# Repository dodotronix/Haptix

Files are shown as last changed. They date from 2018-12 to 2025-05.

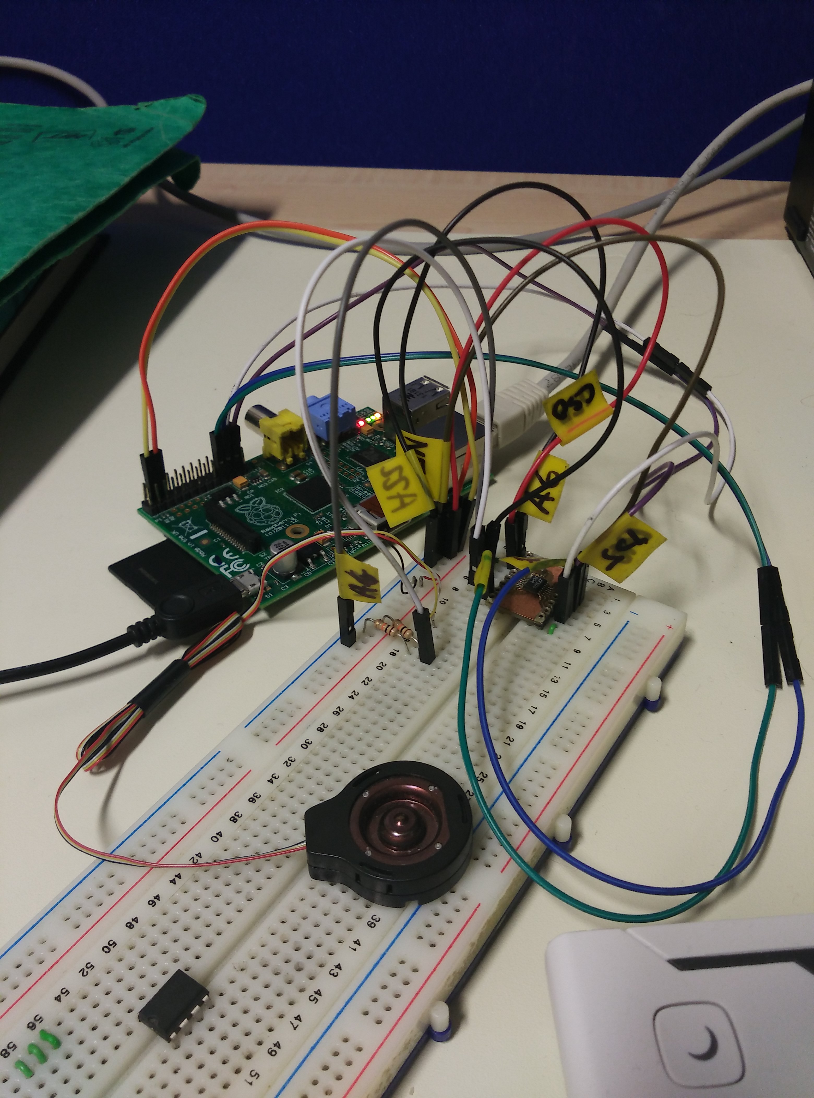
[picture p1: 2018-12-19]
analysis/hw/IMG_20181219_160500.jpg

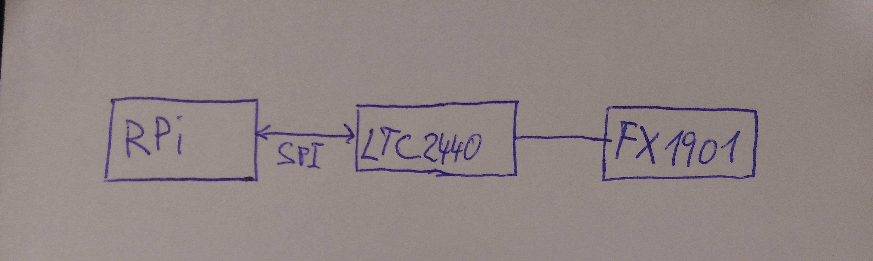
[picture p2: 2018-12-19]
analysis/hw/IMG_20181219_160821.jpg

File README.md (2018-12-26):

## HAPTIX

### INSTALL
* install Archlinux on SD card (https://archlinuxarm.org/platforms/armv6/raspberry-pi)
* turn on RPi
* use ssh or keyboard and display to continue in installation

* update system with
> pacman -Syu
* download 
> pacman -S python 
* download snap shot from link: https://aur.archlinux.org/packages/python-spidev/
* open terminal -> cd /path/to/file -> tar xzf file-name -> cd file-name ->
makepkg -s -> sudo pacman -U name-of-file.pkg.tar.xz
* copy test.py to raspberry
* cd /path/to/test.py
* chmod +x test.py
* ./test.py
* you select functions in script, which you want to run

### NOTES
* spidev doc (https://github.com/doceme/py-spidev)
* raspberry ssh command: ssh alarm@10.0.4.x, password: "alarm" (custom settings)
* sudo iptables -t nat -vnL
* setup.sh creates nat, starts dhcpcd, launchs ssh (parameters: on/off)

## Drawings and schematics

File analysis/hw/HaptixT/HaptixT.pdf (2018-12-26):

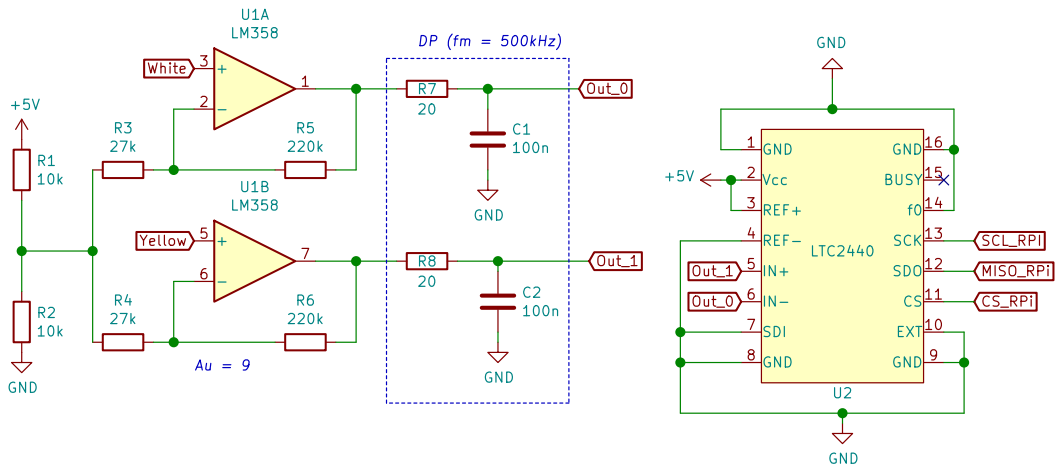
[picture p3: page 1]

File: HaptixT.sch Sheet: /
Id: 1/1 Title:

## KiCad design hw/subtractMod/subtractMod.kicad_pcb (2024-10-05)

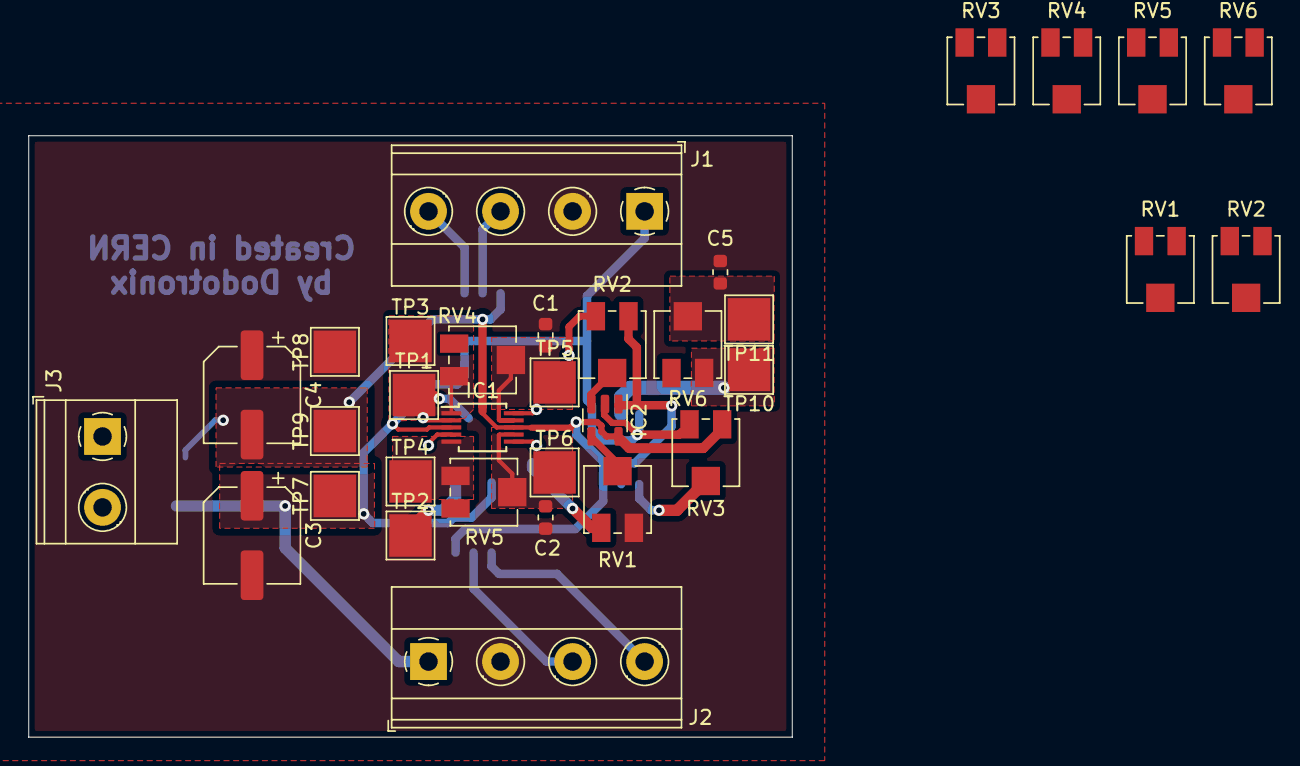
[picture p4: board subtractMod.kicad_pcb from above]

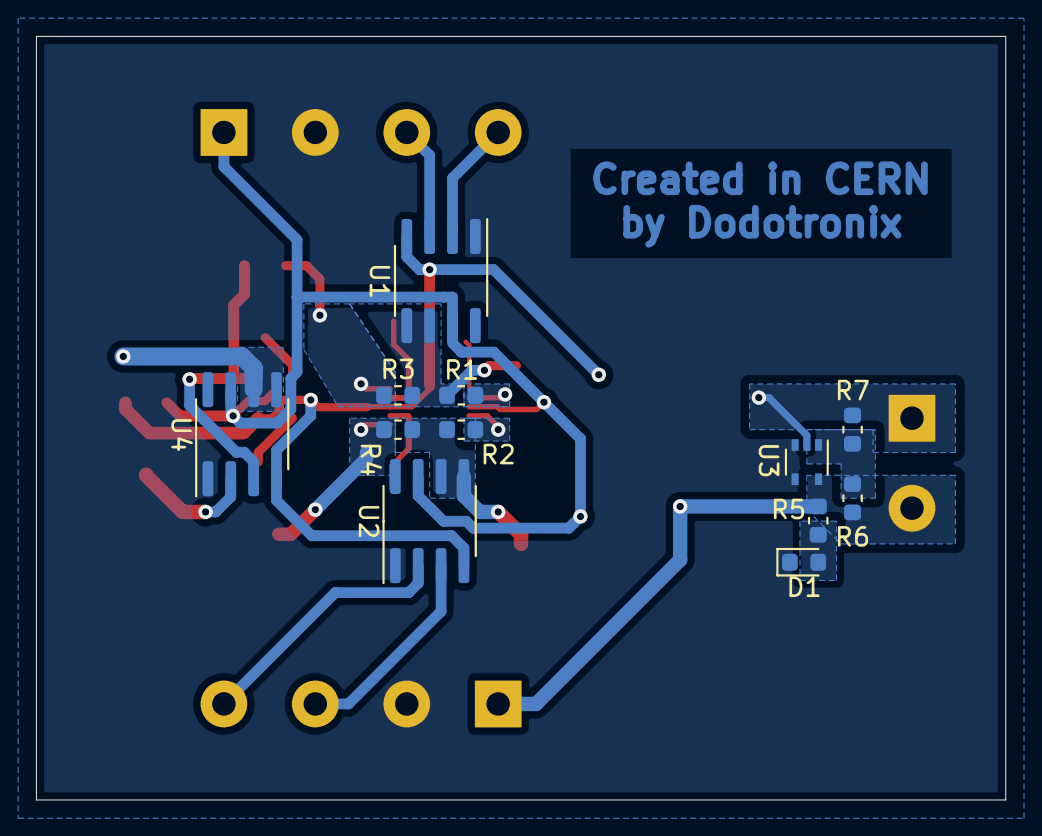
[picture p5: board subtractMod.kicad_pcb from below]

Board: 2 copper layers, 53.8 x 42.4 mm, 45 parts (12 on the bottom side), 25 nets.

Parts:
C1, C2, C5: C; C_0603_1608Metric
C3, C4: 47u; CP_Elec_6.3x5.9
D1: LED; LED_0603_1608Metric
IC1: AD8244; MSOP-10_3x3mm_P0.5mm
IC2: LMP2011; SOT-23-5
J1, J2: Screw_Terminal_01x04; TerminalBlock_Phoenix_MKDS-1,5-4-5.08_1x04_P5.08mm_Horizont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
J3: Screw_Terminal_01x02; TerminalBlock_Phoenix_MKDS-1,5-2_1x02_P5.00mm_Horizontal
R1, R2, R3, R4: 0R; R_0603_1608Metric
R5: R; R_0603_1608Metric
R6, R7: 10k; R_0603_1608Metric
RV1, RV2, RV3, RV4, RV5, RV6: R_POT_TRIM; Potentiometer_Bourns_3314J_Vertical
RV1#2, RV2#2, RV3#2, RV4#2, RV5#2, RV6#2: R_Potentiometer_Trim; Potentiometer_Bourns_3314J_Vertical
TP1, TP2, TP3, TP4, TP5, TP6, TP7, TP8, TP9, TP10, TP11: TestPoint; TestPoint_Pad_3.0x3.0mm
U1, U2, U4: AD8276; SOIC-8_3.9x4.9mm_P1.27mm
U3: TLV6001DCK; SOT-353_SC-70-5

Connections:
+5V: C3.1, IC1.3 (+V), IC2.5 (+V), J1.1, J2.1, J3.2, R5.1, R6.1, RV3.3, RV5#2.1, TP7.1, U1.7 (V+), U2.7 (V+), U3.5 (V+), U4.7 (V+)
-5V: C4.2, IC1.8 (-V), IC2.2 (-V), J3.1, R7.2, RV3.1, RV5#2.3, TP9.1, U1.4 (V-), U2.4 (V-), U3.2 (V-), U4.4 (V-)
/Input_channel/chan1_out: IC1.4 (OutB), R3.1, RV3#2.3
/Input_channel/chan2_out: IC1.9 (OutD), R4.1, RV4#2.1
/Input_channel/sensA_out: R1.2, R3.2, TP1.1, U1.5 (SENSE), U1.6
/Input_channel/sensB_out: R2.2, R4.2, TP2.1, U2.5 (SENSE), U2.6
GND: C1.2, C2.2, C3.2, C4.1, C5.2, D1.1 (K), J1.2, J2.2, RV1.3, RV4#2.3, TP8.1, U1.1 (REF), U2.1 (REF), U3.3 (-), U3.4, U4.1 (REF)
unnamed: C5.1, RV6.2, RV6#2.2, TP11.1
unnamed: D1.2 (A), R5.2
unnamed: IC1.1 (InA), R1.1
unnamed: IC1.2 (OutA), RV1#2.1, TP3.1
unnamed: C1.1, IC1.5 (InB), RV1#2.2, TP5.1
unnamed: IC1.6 (InC), R2.1
unnamed: IC1.7 (OutC), RV2#2.1, TP4.1
unnamed: C2.1, IC1.10 (InD), RV2#2.2, TP6.1
unnamed: IC2.3 (V+), RV3#2.2
unnamed: IC2.4 (V-), RV4#2.2
unnamed: IC2.1 (Vout), RV3#2.1, U4.3 (+)
unnamed: J1.3, U1.3 (+)
unnamed: J1.4, U1.2 (-)
unnamed: J2.3, U2.3 (+)
unnamed: J2.4, U2.2 (-)
unnamed: R6.2, R7.1, U3.1 (+)
unnamed: RV5#2.2, U4.2 (-)
unnamed: RV6#2.1, TP10.1, U4.5 (SENSE), U4.6

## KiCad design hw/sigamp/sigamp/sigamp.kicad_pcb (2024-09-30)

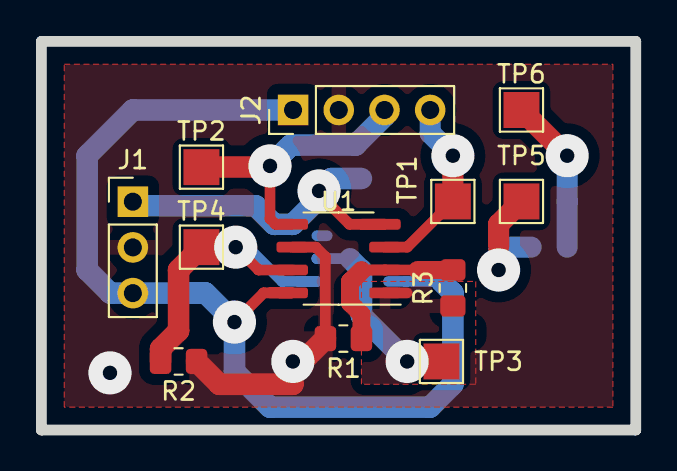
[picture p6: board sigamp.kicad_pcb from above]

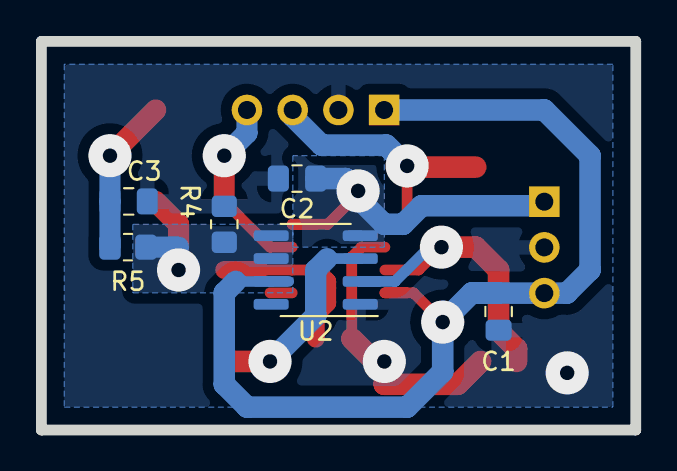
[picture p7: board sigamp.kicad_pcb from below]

Board: 2 copper layers, 33.0 x 21.6 mm, 18 parts (6 on the bottom side), 10 nets.

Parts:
C1, C2: 100n; C_0805_2012Metric_Pad1.18x1.45mm_HandSolder
C3: C; C_0805_2012Metric_Pad1.18x1.45mm_HandSolder
J1: Conn_01x03; PinHeader_1x03_P2.54mm_Vertical
J2: Conn_01x04; PinHeader_1x04_P2.54mm_Vertical
R1, R2, R3, R4, R5: R; R_0805_2012Metric_Pad1.20x1.40mm_HandSolder
TP1, TP2, TP3, TP4, TP5, TP6: TestPoint; TestPoint_Pad_2.0x2.0mm
U1: LM358; SO-8_3.9x4.9mm_P1.27mm
U2: AD8276; SOIC-8_3.9x4.9mm_P1.27mm

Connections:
+5V: C1.1, J1.3, J2.1, U1.8 (V+), U2.7 (V+)
-5V: C2.1, J1.1, U1.4 (V-), U2.4 (V-)
/s+: J2.4, TP1.1, U1.3 (+)
/s-: J2.3, TP2.1, U1.5 (+)
GND: C1.2, C2.2, C3.2, J1.2, J2.2, R1.2, R2.1, R4.1, U1.6 (-), U2.1 (REF)
unnamed: C3.1, R5.1, TP6.1
unnamed: R1.1, R3.2, U1.2 (-)
unnamed: R2.2, TP4.1, U1.7, U2.2 (-)
unnamed: R3.1, TP3.1, U1.1, U2.3 (+)
unnamed: R4.2, R5.2, TP5.1, U2.5 (SENSE), U2.6

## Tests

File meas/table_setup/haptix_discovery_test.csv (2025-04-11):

#Digilent WaveForms Oscilloscope Acquisition
#Device Name: Discovery3
#Serial Number: SN:210415BCB78D
#Date Time: 2025-03-28 16:28:17.887.605.610
#Sample rate: 10000Hz
#Samples: 16384
#Trigger: Source: Channel 1 Type: Edge Condition: Rising Level: 50 mV Hyst.: Auto HoldOff: 0 s
#Channel 1: Range: 1 V/div Offset: 0 V Probe: 10 X Sample Mode: Average
#Channel 2: Range: 200 mV/div Offset: 0 V Probe: 10 X Sample Mode: Average
Time (s) | Channel 1 (V) | Channel 2 (V)
-0.8191273972602741 | 0.03404938981463987 | 0.01975503185556442
-0.8190273972602741 | 0.03404938981463987 | 0.02054684958813206
-0.818927397260274 | 0.0316765487096568 | 0.01896321412299606
-0.818827397260274 | 0.0316765487096568 | 0.01896321412299606
-0.818727397260274 | 0.03246749574465116 | 0.01975503185556442
-0.818627397260274 | 0.0316765487096568 | 0.01975503185556442
-0.818527397260274 | 0.03088560167466245 | 0.02054684958813278
-0.818427397260274 | 0.0316765487096568 | 0.01975503185556442
-0.818327397260274 | 0.03009465463966809 | 0.02054684958813278
-0.818227397260274 | 0.0316765487096568 | 0.0221304850532695
-0.8181273972602741 | 0.0316765487096568 | 0.02133866732070114
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

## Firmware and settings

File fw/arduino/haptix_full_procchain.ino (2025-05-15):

// 1) start the digilent analog discovery power supply +-5V 
// 2) don't forget to check, if all the grounds have shortest
// track to the AD3 extension board with BENC connectors
// 3) run the program

#define YELLOW 6
#define BLUE 7
#define TIMER_PERIOD 58015 // Ts = 470us

#define Q 15 
#define ONE_Q 32767
#define ADC_WIDTH 9 // NOTE multiply your signal by pow2
#define ADC_TO_Q115( x ) ( (x - 512) << (Q - ADC_WIDTH) )

#define BUTTER_SIZE 3
#define BUFFER_SIZE 8
#define BUFFER_MASK (BUFFER_SIZE) - 1
#define OFFSET_MEAS_LENGTH 4 // i can go up to 16
#define DLY 6

#define ZERO_SCORE_EXTEND 2
#define ZERO_SCORE_ALPHA 2621 // 0.08
#define ZERO_SCORE_NOISE  800 // 0.025
#define ZERO_SCORE_THRES (2UL << Q)
#define ZERO_SCORE_OFFSET 200

// this defines the conversion steps of the sqrt if
// you change it, you have to regenerate the LUT
#define SQRT_PRECISION 6

// needs to be power of 2
#define ZERO_SCORE_LAGS 64

// NOTE don't forget to change DIV, 
// if you change the ZERO_SCORE_LAGS
#define ZERO_SCORE_DIV 6

#define FACTOR 18678 // 0.57
// #define FACTOR 32767 // ~1

#include <stdio.h>
#include <stdlib.h>
#include <Adafruit_MCP3008.h>

// constants (LPF freq. cutoff 30Hz)
const int32_t a[3] = {32767, -61435, 28909};
const int32_t b[3] = {60, 121, 60};

typedef struct {
    int in[BUFFER_SIZE];
    int out[BUFFER_SIZE];
    int offset;
    int factor;
    uint8_t dly;
    uint8_t head;
} BF_t; // input filter circular buffer

typedef struct {
    int buffer[ZERO_SCORE_LAGS];
    int avg;
    int var;
    int filtered;
    unsigned char head;
} ZSD_t; // zero-score detector

// input format q1.(15 + 2*EXTEND + DIV - PRECISION) -> sqrt() -> q1.15
int sqrt_lut [256] = {
    0,  45,  64,  78,  91, 101, 111, 120, 128, 136,
  143, 150, 157, 163, 169, 175, 181, 187, 192, 197,
  202, 207, 212, 217, 222, 226, 231, 235, 239, 244,
  248, 252, 256, 260, 264, 268, 272, 275, 279, 283,
  286, 290, 293, 297, 300, 304, 307, 310, 314, 317,
  320, 323, 326, 329, 333, 336, 339, 342, 345, 348,
  351, 353, 356, 359, 362, 365, 368, 370, 373, 376,
  379, 381, 384, 387, 389, 392, 395, 397, 400, 402,
  405, 407, 410, 412, 415, 417, 420, 422, 425, 427,
  429, 432, 434, 436, 439, 441, 443, 446, 448, 450,
  453, 455, 457, 459, 462, 464, 466, 468, 470, 472,
  475, 477, 479, 481, 483, 485, 487, 490, 492, 494,
  496, 498, 500, 502, 504, 506, 508, 510, 512, 514,
  516, 518, 520, 522, 524, 526, 528, 530, 532, 534,
  535, 537, 539, 541, 543, 545, 547, 549, 551, 552,
  554, 556, 558, 560, 562, 563, 565, 567, 569, 571,
  572, 574, 576, 578, 580, 581, 583, 585, 587, 588,
  590, 592, 594, 595, 597, 599, 600, 602, 604, 605,
  607, 609, 611, 612, 614, 616, 617, 619, 621, 622,
  624, 625, 627, 629, 630, 632, 634, 635, 637, 638,
  640, 642, 643, 645, 646, 648, 650, 651, 653, 654,
  656, 657, 659, 660, 662, 664, 665, 667, 668, 670,
  671, 673, 674, 676, 677, 679, 680, 682, 683, 685,
  686, 688, 689, 691, 692, 694, 695, 697, 698, 700,
  701, 703, 704, 705, 707, 708, 710, 711, 713, 714,
  716, 717, 718, 720, 721, 723
};

int fsqrt(int x){
  int index = (x >> SQRT_PRECISION);
    if (x > 255) return sqrt_lut[255]; 
    else return sqrt_lut[x];
}

// NOTE pramater a can be bigger 
// than one up to certain extend
// this is intended to be used 
// in the detector function
int fmul(int32_t a, int16_t b){
  int32_t tmp = a*b;
  tmp += (tmp >= 0) ? (1 << (Q - 1)) : -(1 << (Q - 1));

  // NOTE: due to the C/C++ signed/unsigned type implementation 
  // shifting negative number will never reach 0 but always -1, 
  // therefore we have to check the condition manually, by
  // checking the abs() of the vaule
  if(!(abs(tmp) >> Q)) {
    return 0;
  }

  tmp >>= Q;

  // saturation
  if (tmp > ONE_Q) {
    return (int) ONE_Q;
  } else if (tmp < -(ONE_Q + 1)) {
    return (int) -(ONE_Q + 1);
  }

  return (int)tmp;
}

void butter_init(BF_t *filter, int offset, int factor, uint8_t dly){
    filter->head = 0;
    filter->dly = dly;
    filter->factor = factor;
    filter->offset = offset;
    memset(filter->in, 0, sizeof(filter->in));
    memset(filter->out, 0, sizeof(filter->out));
}

int butter_get_nth(BF_t *filter, unsigned char n) {
  unsigned char index = (filter->head - n) & BUFFER_MASK;
  return filter->out[index];
}

// butterworth filter function 
int butter_push(BF_t *filter, int value) {
    // shift in the new value
    filter->head = (filter->head + 1) & BUFFER_MASK;
    int obtained = value - filter->offset;
    filter->in[filter->head] = fmul(filter->factor, obtained);

    int result = 0; 
    for (int i = 0; i < BUTTER_SIZE; ++i) {
        int idx = (filter->head - filter->dly - i) & BUFFER_MASK;
        result += fmul(b[i], filter->in[idx]);
    }

    for (int i = 1; i < BUTTER_SIZE; ++i) {
        int idx = (filter->head - i) & BUFFER_MASK;
        result -= fmul(a[i], filter->out[idx]);
    }

    filter->out[filter->head] = result;
    return result;
}

void detector_init(ZSD_t *d){
    d->head = 0;
    d->avg = 0;
    d->var = 0;
    d->filtered = 0;
    memset(d->buffer, 0, sizeof(d->buffer));
}

void detector_update( ZSD_t *d, int *event, int value){

    // classification
    int input = abs(value - (d->avg >> ZERO_SCORE_DIV));
    int limit = fmul(ZERO_SCORE_THRES, fsqrt(d->var)) + ZERO_SCORE_OFFSET;

    if (input > limit){
      d->filtered += fmul(ZERO_SCORE_ALPHA, (value - d->filtered));

      if ((value > (d->avg >> ZERO_SCORE_DIV)) && (input > ZERO_SCORE_NOISE) && !(*event))
        *event = 1;

    } else {
       d->filtered = value;

       // NOTE since it's a demo, we use 
       // static value to reset the event 
       // variable
       if((value < 1000) && (*event)) 
         *event = 0;
    }

    // save previous states before updating
    int l_avg = d->avg;
    int aa = d->filtered - d->buffer[d->head];

    // update average and variance
    d->avg += aa;
    int c = ((d->avg + l_avg) >> ZERO_SCORE_DIV);
    int bb = d->filtered - c + d->buffer[d->head];
    d->var += fmul((aa << ZERO_SCORE_EXTEND), (bb << ZERO_SCORE_EXTEND));

    // variance cannot be negative
    if (d->var < 0)
      d->var = 0;

    // update circular buffer
    d->buffer[d->head] = d->filtered;
    d->head = (d->head + 1) & (ZERO_SCORE_LAGS - 1);
}

Adafruit_MCP3008 adc;
volatile uint8_t trigger = 0;
int measured[2] = {0, 0};
int signal, event;
BF_t force, accel;
ZSD_t detector;

void setup() {

  int32_t offset[2] = {0, 0};
  event = 0;

  cli();
  TCCR1A = 0;           // Init Timer1A
  TCCR1B = 0;           // Init Timer1B
  TCCR1B |= B00000001;  // Prescaler = 1
  TCNT1 = TIMER_PERIOD;        // Timer Preloading
  TIMSK1 |= B00000001;  // Enable Timer Overflow Interrupt
  sei();

  Serial.begin(115200);
  while (!Serial);

  Serial.println("[INFO] Haptix initialization sequence");
  Serial.println("");

  // set pins 
  pinMode(YELLOW, OUTPUT);
  pinMode(BLUE, OUTPUT);

  // initialize ADC
  adc.begin(10);

// find offset
#if OFFSET_MEAS_LENGTH
    for(int i=0; i<OFFSET_MEAS_LENGTH; ++i) {
      while(!trigger); //wait for trigger
      measured[0] = adc.readADC(0);
      measured[1] = adc.readADC(1);
      offset[0] += ADC_TO_Q115(measured[0]);
      offset[1] += ADC_TO_Q115(measured[1]);
    }

    // rounding and division
    offset[0] = ((offset[0] + (1 << 1)) >> 2);
    offset[1] = ((offset[1] + (1 << 1)) >> 2);
#endif

  Serial.print("[INFO] offset force: ");
  Serial.println((int)offset[0]);
  Serial.print("[INFO] offset acceleration: ");
  Serial.println((int)offset[1]);

  // initialize input buffer
  Serial.println("[INFO] Initialize Butterworth filter");
  butter_init(&force, (int)offset[0], ONE_Q, DLY);
  butter_init(&accel, (int)offset[1], FACTOR, 0);

  // initialize edge detector
  Serial.println("[INFO] Initialize detector");
  detector_init(&detector); 
}

ISR(TIMER1_OVF_vect){
  TCNT1 = TIMER_PERIOD; // Timer Preloading
  trigger = 1;
}

void loop() {
  if(trigger){
    trigger = 0;
    digitalWrite(YELLOW, HIGH);

    // measure new samples 
    measured[0] = adc.readADC(0);
    measured[1] = adc.readADC(1);

    // processing chain
    signal = butter_push(&force, ADC_TO_Q115(measured[0]));
    signal -= butter_push(&accel, ADC_TO_Q115(measured[1]));
    detector_update(&detector, &event, signal);

    // toggle active state until the 
    // signal sinks close to the zero 
    // if(signal > 100) event = 1;
    // else event = 0;

    // activate indicator
    if(event) digitalWrite(BLUE, HIGH);
    else digitalWrite(BLUE, LOW);

    digitalWrite(YELLOW, LOW);
  }
}

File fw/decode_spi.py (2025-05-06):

#!/usr/bin/python

# -*- coding: utf-8 -*-
#
# Copyright (C) 2022 Dododtronix
#
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
# You can dowload a copy of the GNU General Public License here:
# http://www.gnu.org/licenses/gpl.txt

import numpy as np
import matplotlib.pyplot as plt

from ctypes import *
from sys import platform, path
from os import sep
from time import sleep

dwf = cdll.LoadLibrary("libdwf.so")
constants_path = (f"{sep}usr{sep}share{sep}digilent"
                  f"{sep}waveforms{sep}samples{sep}py")

#import constants
path.append(constants_path)
from dwfconstants import *

hdwf = c_int()
sts = c_byte()

dwf.FDwfDeviceOpen(c_int(-1), byref(hdwf))
if hdwf.value == 0:
    print("Failed to open device")
    exit()

# SET Voltage
# set up analog IO channel V+
print("Power supply setup")
dwf.FDwfAnalogIOChannelNodeSet(hdwf, c_int(0), c_int(0), c_double(1)) 
dwf.FDwfAnalogIOChannelNodeSet(hdwf, c_int(1), c_int(0), c_double(1)) 
# set voltage to 5 V
dwf.FDwfAnalogIOChannelNodeSet(hdwf, c_int(0), c_int(1), c_double(5.0)) 
dwf.FDwfAnalogIOChannelNodeSet(hdwf, c_int(1), c_int(1), c_double(-5.0)) 
# enable voltage
dwf.FDwfAnalogIOEnableSet(hdwf, c_int(1))

sleep(1)

channel = c_int(0)
dwf.FDwfAnalogOutNodeEnableSet(hdwf, channel,    AnalogOutNodeCarrier, c_int(1))
dwf.FDwfAnalogOutNodeFunctionSet(hdwf, channel,  AnalogOutNodeCarrier, funcSine)
dwf.FDwfAnalogOutNodeFrequencySet(hdwf, channel, AnalogOutNodeCarrier, c_double(300))
dwf.FDwfAnalogOutNodeAmplitudeSet(hdwf, channel, AnalogOutNodeCarrier, c_double(2.4))
dwf.FDwfAnalogOutNodeOffsetSet(hdwf, channel,    AnalogOutNodeCarrier, c_double(2.4))

print("Generating sine wave...")
dwf.FDwfAnalogOutConfigure(hdwf, channel, c_int(1))

nSamples = 100000 # 100MiB, ~12Mi of 8bit SPI
rgbSamples = (c_uint8*nSamples)()
nWords = 4000

idxClk = 0 # DIO-0
idxMiso = 1 # DIO-1
idxMosi = 2 # DIO-2
idxCS = 3 # DIO-3
nBits = 8 # 8-bit words

# record mode
dwf.FDwfDigitalInAcquisitionModeSet(hdwf, acqmodeRecord)
# for sync mode set divider to -1 
dwf.FDwfDigitalInDividerSet(hdwf, c_int(-1))
# 8bit per sample format, DIO 0-7
dwf.FDwfDigitalInSampleFormatSet(hdwf, c_int(8))

# continuous measurement
dwf.FDwfDigitalInTriggerPositionSet(hdwf, c_int(-1))
dwf.FDwfDigitalInTriggerSet(hdwf, c_int(0), c_int(0), c_int((1<<idxClk)|(1<<idxCS)), c_int(0))
dwf.FDwfDigitalInConfigure(hdwf, c_int(0), c_int(1))

cAvailable = c_int()
cLost = c_int()
cCorrupted = c_int()

fsMosi = 0
fsMiso = 0
cBit = 0
rgMosi = []
rgMiso = []

channels = [[], []] #, []]

def info(decoded_data):
    if decoded_data:
        tmp = [f"0x{n:02x}" for n in decoded_data] 
        return ', '.join(tmp)

print("Start acquisition")

# wait for acquisition
while True:
    dwf.FDwfDigitalInStatus(hdwf, c_int(1), byref(sts))
    dwf.FDwfDigitalInStatusRecord(hdwf, byref(cAvailable), byref(cLost), byref(cCorrupted))
    dwf.FDwfDigitalInStatusData(hdwf, rgbSamples, c_int(cAvailable.value))

    if cAvailable.value or cLost.value or cCorrupted.value:
        print(f"available: {cAvailable.value}, lost: {cLost.value}, corrupted: {cCorrupted.value}")

    for i in range(cAvailable.value):
        v = rgbSamples[i]
        if (v>>idxCS)&1: # CS high
            print(f"MOSI: {info(rgMosi)} | MISO: {info(rgMiso)}")
            if cBit != 0: # log leftover bits, frame not multiple of nBits
                print("leftover bits %d : h%02X | h%02X" % (cBit, fsMosi, fsMiso))

            try:
                if(rgMosi[1] ==  0x80):
                    channels[0].append(((rgMiso[1] & 0x07) << 8) | rgMiso[2])
                if(rgMosi[1] ==  0x90):
                    channels[1].append(((rgMiso[1] & 0x07) << 8) | rgMiso[2])
                # if(rgMosi[1] ==  0xa0):
                #     channels[2].append(((rgMiso[1] & 0x07) << 8) | rgMiso[2])
            except:
                pass

            if((len(channels[0]) == nWords) and \
                   (len(channels[1]) == nWords)): 
                #and (len(channels[2]) == nWords)):
               break 

            cBit, fsMosi, fsMiso = 0, 0, 0
            rgMosi.clear()
            rgMiso.clear()
        else:
            cBit+=1
            fsMosi <<= 1 # MSB first
            fsMiso <<= 1 # MSB first
            if (v>>idxMosi)&1 :
                fsMosi |= 1
            if (v>>idxMiso)&1 :
                fsMiso |= 1
            if cBit >= nBits: # got nBits of bits
                rgMosi.append(fsMosi)
                rgMiso.append(fsMiso)
                cBit = 0
                fsMosi = 0
                fsMiso = 0

    if((len(channels[0]) == nWords) and \
           (len(channels[1]) == nWords)):
        #and (len(channels[2]) == nWords)):
       break 

dwf.FDwfDeviceClose(hdwf)

channels = np.array(channels).T

plt.plot(channels, marker='')
plt.title("Visualization of SPI received data")
plt.xlabel("Sample Index [-]")
plt.ylabel("ADC value [-]")
plt.grid(True)
plt.show()

# Save the data to csv for post-processing
np.savetxt("channels.csv", 
           channels,
           delimiter=",", 
           header="Force,accelX,accelY", 
           comments='',
           fmt='%.4f')

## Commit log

2018-12-18 spi test
2018-12-26 scheme of wiring of DUT
    [HaptixT.kicad_pcb, HaptixT.sch]
2020-02-29 pcb for signal subtraction test
    [In_channel.sch, offset_ctrl.sch, power_block.sch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]
2020-03-02 changed tracks width
    [subtractMod.kicad_pcb]
2020-03-11 added component webpages and datasheets
    [In_channel.sch, offset_ctrl.sch, power_block.sch]
2021-06-15 signal amplifier for load cell sensor reliability test
    [sigamp.kicad_pcb, sigamp.kicad_sch]
2024-09-06 created new empty script to simulate kinematics of the grinder
2024-09-10 fixed wrong calculation of the decelation stage
2024-09-13 refactored kinematic_model script and renamed to demo.m
2024-09-14 removed redundant printouts
2024-09-17 added i2c class to control the accelerometer
2024-09-17 prototype of pkgbuild for bno08x library for archlinux
2024-09-17 package to build latest circuitpython bno08x library
2024-09-17 created new arch package circuitpython-busdevice
2024-09-17 created new package circuitpython-typing
2024-09-21 tested different speeds of i2c - chip uses stretching and lower clock speed does not work
2024-09-21 added spi, it seems to be responding, but the ft232h bridge does not support cpha=1
2024-09-21 ft232h seems to work with mpu6050 accelerometer
2024-09-21 new bno08x circuitpython library for archlinux
2024-09-21 new mpu6050 circuitpython library for archlinux
2024-09-21 new circuitpython register library for archlinux
2024-09-25 missing circuitpython in the package name
2024-09-30 updated kicad file version
    [sigamp.kicad_pcb, sigamp.kicad_sch]
2024-10-05 scripts for haptix tests
    [In_channel.kicad_sch, offset_ctrl.kicad_sch, power_block.kicad_sch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]
2024-10-05 updated schematics of subtraction module
    [In_channel.kicad_sch, offset_ctrl.kicad_sch, power_block.kicad_sch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]
2024-10-14 created circuit python accelerometer and storage test
2024-10-18 measurement in micrometers of the force sensor
2024-10-22 load cell and accelerometer tests
2024-11-30 kalman filter test from the book
2025-01-24 schematics of the new attempts to use instrumentation amplifier and analog accelerometer
    [load_cell_amplifier.kicad_pcb, load_cell_amplifier.kicad_sch]
2025-02-27 updated contact array circuit
    [load_cell_amplifier.kicad_sch]
2025-02-27 measured shaking signals on the table setup
    [data.csv]
2025-03-03 adjusted code to test accelerometer and load cell data processing
2025-03-03 updated version of kicad
    [load_cell_amplifier.kicad_sch]
2025-04-09 haptix arduino uno r3 test
2025-04-10 updated - the adafruit library supports just spi freq 1MSmp, timer set to 150us (~6khz)
2025-04-11 code to visualise data read from the mcp3008 adc using arduino
2025-04-11 table setup data in the lab
    [haptix_discovery_test.csv, table_setup_matching.csv, table_setup_matching1.csv]
2025-04-11 new demo to check the matching of the two sensors signals
2025-04-11 updated kicad version
    [load_cell_amplifier.kicad_pcb, load_cell_amplifier.kicad_sch]
2025-04-17 loaded new data with sampled vibration process measured on the arduino setup
2025-04-17 arduino setup vibration process data
    [channels_simple_vibration.csv]
2025-05-02 added input delay to the butterworth filter
2025-05-02 created prototype of the detection chain - needs to be verified in python and changed to use fixed point math
2025-05-06 this script is testing the fixed point math to be implemented on arduino
2025-05-06 highlevel dsp chain development
2025-05-06 quick visual verification of the code functionality implemented partially in arduino
2025-05-06 implementation of butterworth filter with delay, offset and multiplication factor
2025-05-08 detection simplified to zero-score and simple subtraction of the load cell and accelerometer signals
2025-05-10 created prototypes of the detector and input butterworth filter on arduino - verified in python
2025-05-11 arduino core application moved to arduino folder
2025-05-11 simple butterworth filtering, scaling and subtraction of the signals
2025-05-11 generated iir constants for cutoff freq 120Hz
2025-05-11 first version of the detection procedure on arduino - not tunned yet
2025-05-11 division after avg and var update resolved through macro
    [haptix_full_procchain.ino]
2025-05-12 removed outdated dsp arduino python simulation
2025-05-12 processing chain development using fixed point and lut to calculate sqrt, includes cross-check of the fixed point math
2025-05-12 printing the extended version of aa and bb variables to calculate varSum
2025-05-13 print out the sqrt_q LUT table to be able to upload it to arduino
2025-05-14 upgraded detector fixing issues with rounding errors because of too many bitshifts
    [haptix_full_procchain.ino]
2025-05-14 measured signal samples to tune the detector settings in python
    [channels_470us_double_vibration_fz.csv, channels_470us_grinder_simul_fz.csv, channels_470us_offset_vibration_fz.csv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]
2025-05-15 cutoff of the iir reduced to 30Hz for better accelerometer and force signal overlap
2025-05-15 updated arduino script to match the python script settings
2025-05-16 added input force sample set to be able to translate force to weight and normalized with 8bit sample width
2025-05-16 added weight calibration data set with different amplification factor

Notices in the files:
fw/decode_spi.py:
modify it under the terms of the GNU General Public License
